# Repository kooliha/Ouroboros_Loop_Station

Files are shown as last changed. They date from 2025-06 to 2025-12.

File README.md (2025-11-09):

# ♾️ Ouroboros Loop Station
DIY 5-Track Audio Looper

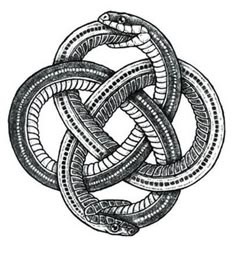
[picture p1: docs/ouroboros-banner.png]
Ouroboros Loop Station


Ouroboros is a DIY 5-track (Layers) stereo loop station designed for musicians, producers, and synth enthusiasts.
Built on the Electrosmith Daisy Seed platform, it offers real-time looping with zero menu diving — just buttons and knobs.

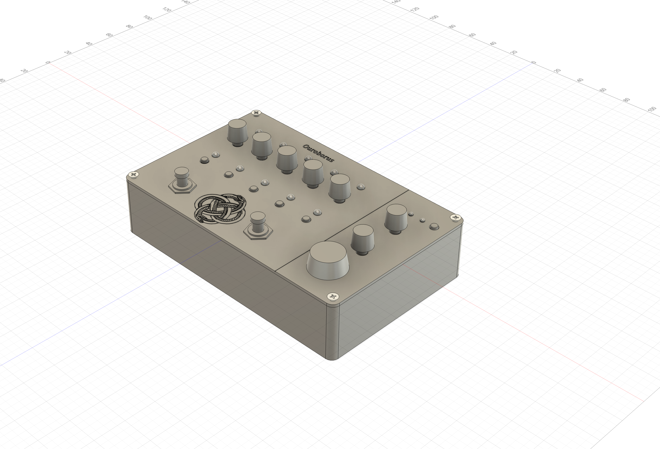
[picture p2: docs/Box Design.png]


## Key Features

- **5 independent stereo tracks** (33 seconds each at 48kHz)
- **Real-time per-track control**:
  - Speed: 0.3× to 2.0×
  - Pan: Left/Right positioning  
  - Volume: Individual + Master
- **Multi-input support**: Guitar, Mic, Line
- **Instant control** — no menus, just hold button + turn knob

## Audio I/O

- 🎸 **Guitar** (Hi-Z)
- 🎤 **Microphone** (with analog preamp)
- 🎧 **Stereo Line In**
- 🔊 **Stereo Output**

## Hardware

- **Daisy Seed** (STM32H750 microcontroller)
- **Through-hole components** only — easy to solder and mod
- **DIY-friendly design**

**Front Side:**
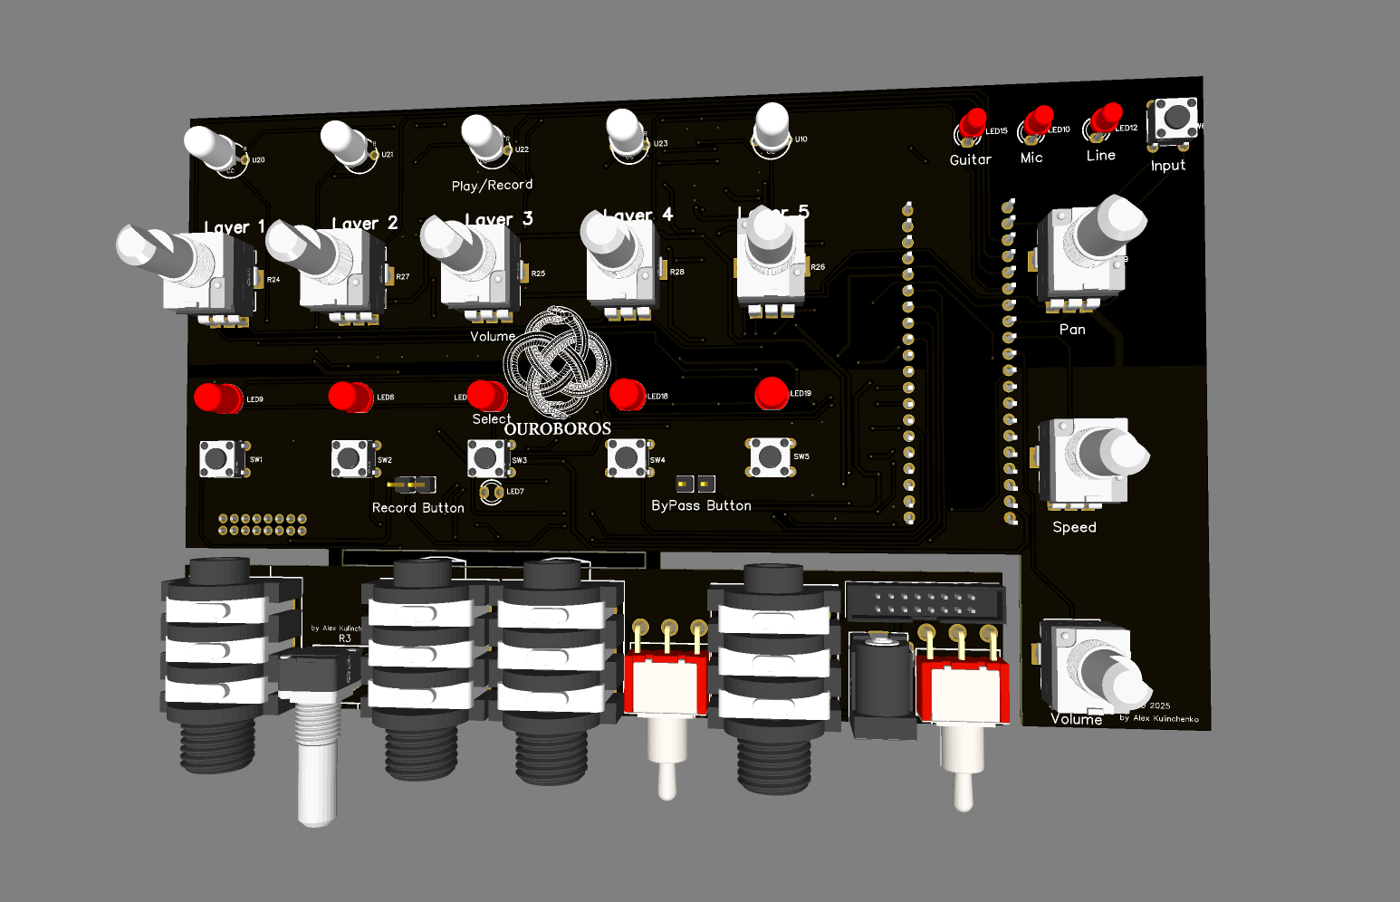
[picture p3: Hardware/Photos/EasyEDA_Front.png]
PCB Front


**Back Side:**
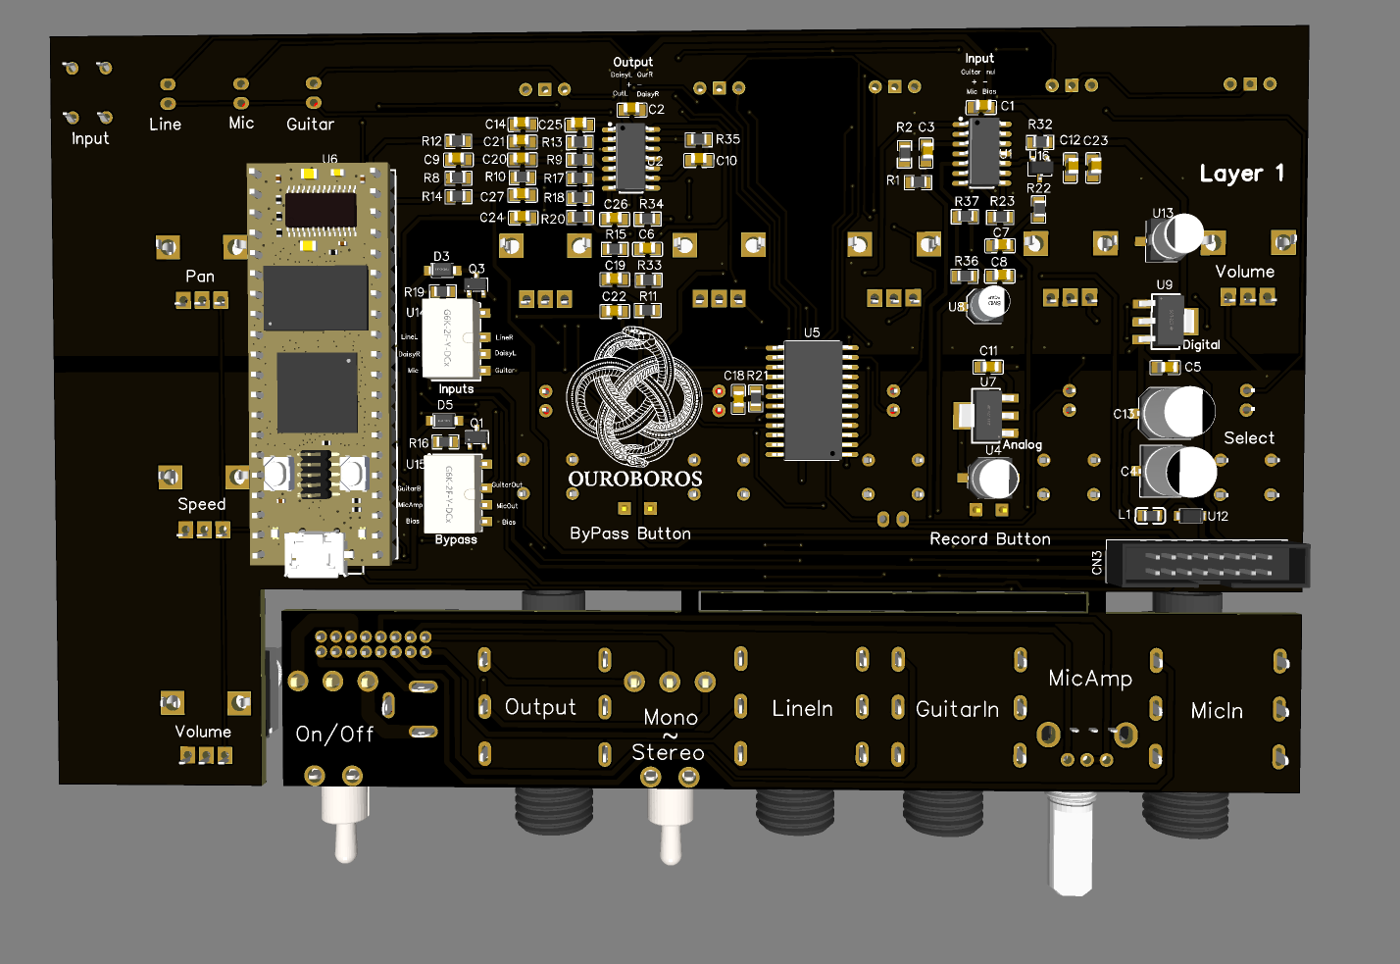
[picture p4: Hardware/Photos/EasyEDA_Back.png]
PCB Back


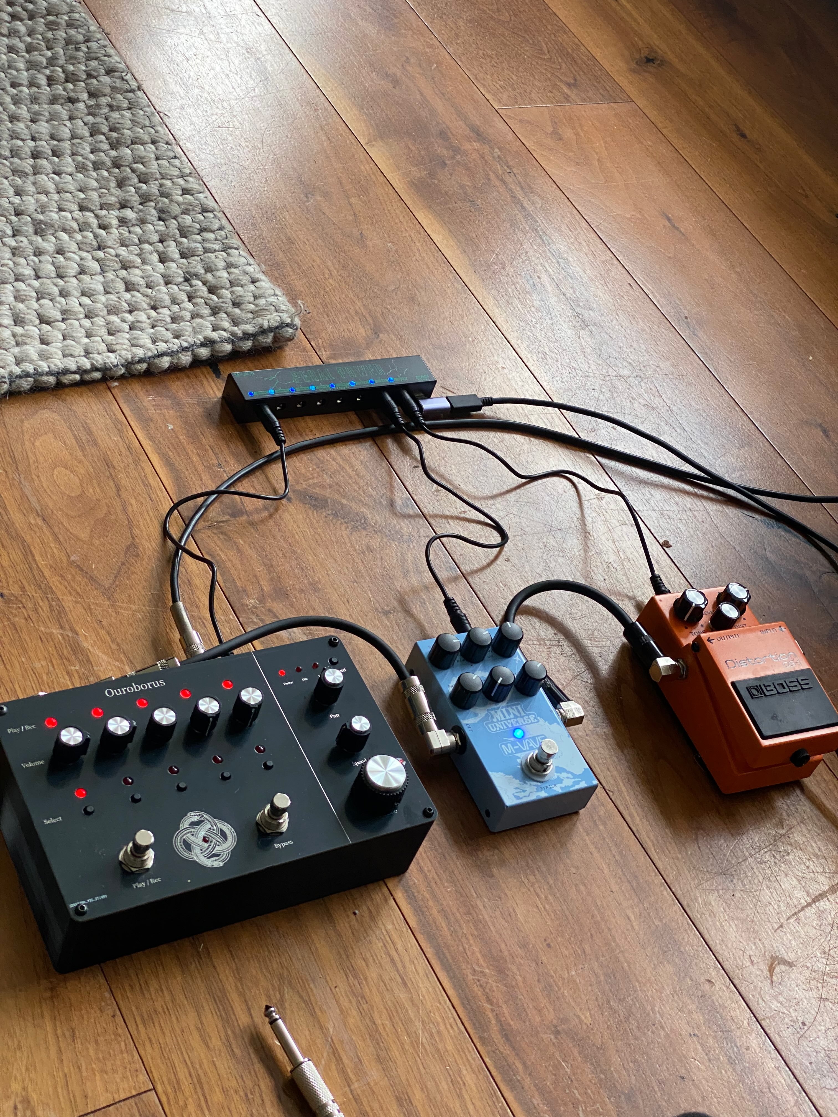
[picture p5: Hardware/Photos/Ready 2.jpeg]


## Hardware
It’s free to use. If you build one and fancy buying me a pint, you can do so here:

[Paypal](https://www.paypal.com/paypalme/AlexKulinchenko)

[Ko-fi.com](https://ko-fi.com/alex_kulinchenko)

Links

* **Schematic**: [PDF](Hardware/Ouroboros%20Schematic%20v1.1-1.2.pdf)
* **PCB v1.1 (Tested)**: [Gerber Files](Hardware/PCB%201.1/PCB_Gerber_1.1.zip)
* **PCB v1.2 (Beta)**: [Gerber Files](Hardware/PCB%201.2/PCB_Gerber_1.2.zip)
* **BOM**: [Excel File](Hardware/BOM_Ouroboros_rev.1.xlsx)
* **3D-printable enclosure**: [3D Files](Hardware/3d%20Printing%20Box%201.1/)
* **Front Panel**: [Design Files](Hardware/Front%20Panel%201.1-1.2/)

## Firmware

Ready-to-flash firmware is available in the `Firmware Master/` folder.

### Flashing Instructions

**Option 1: USB Mass Storage (Easiest)**
1. Download the `.bin` file from [Firmware Master](Firmware%20Master/)
2. Put Daisy Seed in USB Mass Storage mode:
   - Hold **BOOT** button
   - While holding BOOT, press and release **RESET** 
   - Release **BOOT** button
3. Daisy appears as USB drive on your computer
4. Drag and drop the `.bin` file to the USB drive
5. Firmware flashes automatically and Daisy restarts

**Option 2: DFU Flashing**
```bash
make program-dfu
```

**Building from Source**
```bash
make
# Creates main.bin in build/ folder
```

---

Release notes v1.1 (important)

* IDC 16-pin ribbon. I planned to use a standard IDC ribbon to simplify assembly, but I mistakenly used a 1.27 mm pitch instead of 2.54 mm. You’ll either need a matching cable or to hand-wire the connection.
* The output is stereo. Always use a stereo (TRS) jack — a mono plug will short one side of the op-amp. I’ve added protection, but it’s still best to use TRS.
* Analogue and digital grounds are separated and tied at a single point. You must bridge them under the Daisy Seed before power-up. I left this open for easier debugging.
* This PCB does not fit standard Hammond aluminium boxes as-is. Potentially, you can abandon PCB for a socket and fit it with just wires. A 3D-printable enclosure is included.

---

In progress — v1.2 (draft)

I’ve reworked the socket I/O board and corrected the IDC footprint. It should fit a larger Hammond enclosure. If anyone is willing to test the new PCB, you’re very welcome.

* **V1.2 files**: [PCB Gerber Files](Hardware/PCB%201.2/PCB_Gerber_1.2.zip)
* Notes:
  * Socket / I-O board fully redesigned (new layout, different switch/jack footprints).
  * IDC 16-pin footprint corrected; please confirm the pitch before fabrication.

When time allows (between work and family), I plan to design a single-board version combining the Daisy and I/O section, properly sized for a Hammond enclosure.

Feel free to ask questions – always happy to help.

## How to Use

### Recording a Track
1. **Select layer** - Press any layer button (1-5)
2. **Choose input** - Press channel button to cycle: Guitar → Mic → Line
3. **Record** - Hold record button to start recording
4. **Stop** - Release record button to stop and start playback

### Playback Control  
- **Play/Pause** - Single click record button
- **Clear track** - Double click record button
- **Volume** - Turn individual layer volume knob
- **Master volume** - Turn master volume knob

### Real-time Effects
- **Speed control** - Hold any layer button + turn speed knob
- **Pan control** - Hold any layer button + turn pan knob

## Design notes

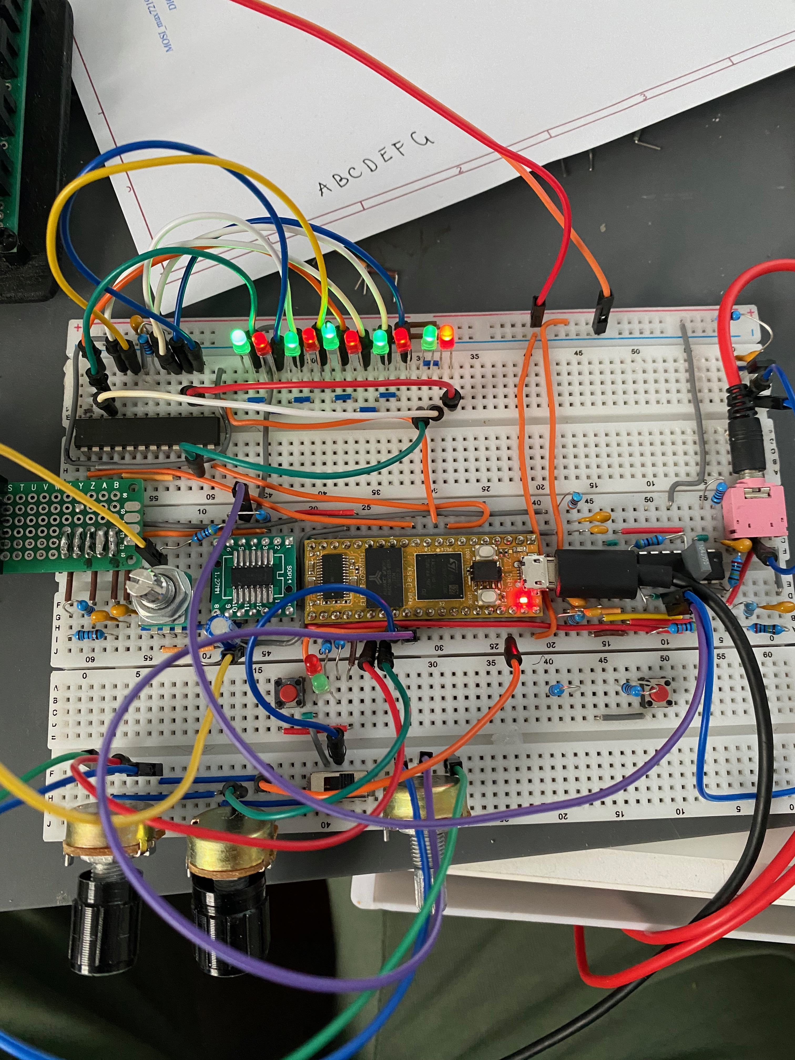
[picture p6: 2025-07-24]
Hardware/Photos/WIP.jpeg

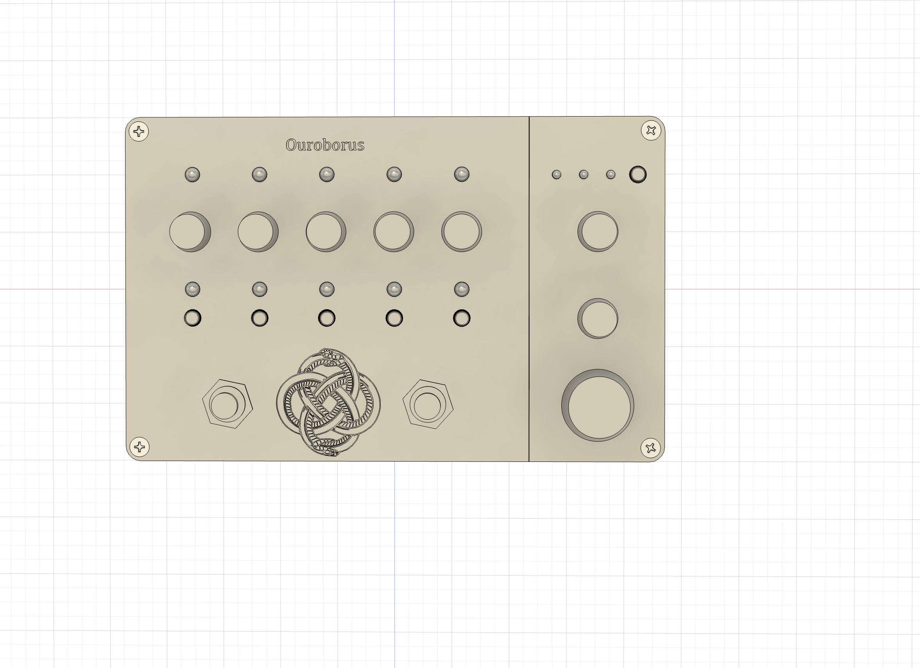
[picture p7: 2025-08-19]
docs/Box Design 2.png

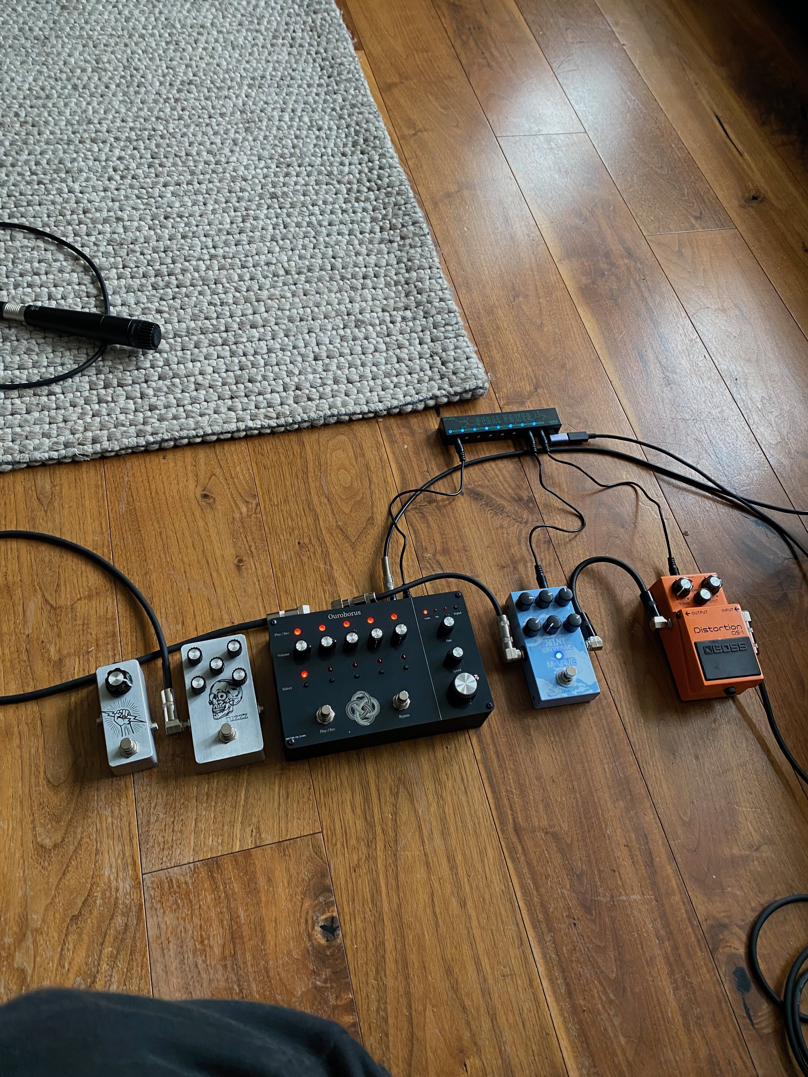
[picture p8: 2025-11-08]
Hardware/Photos/Ready.jpeg

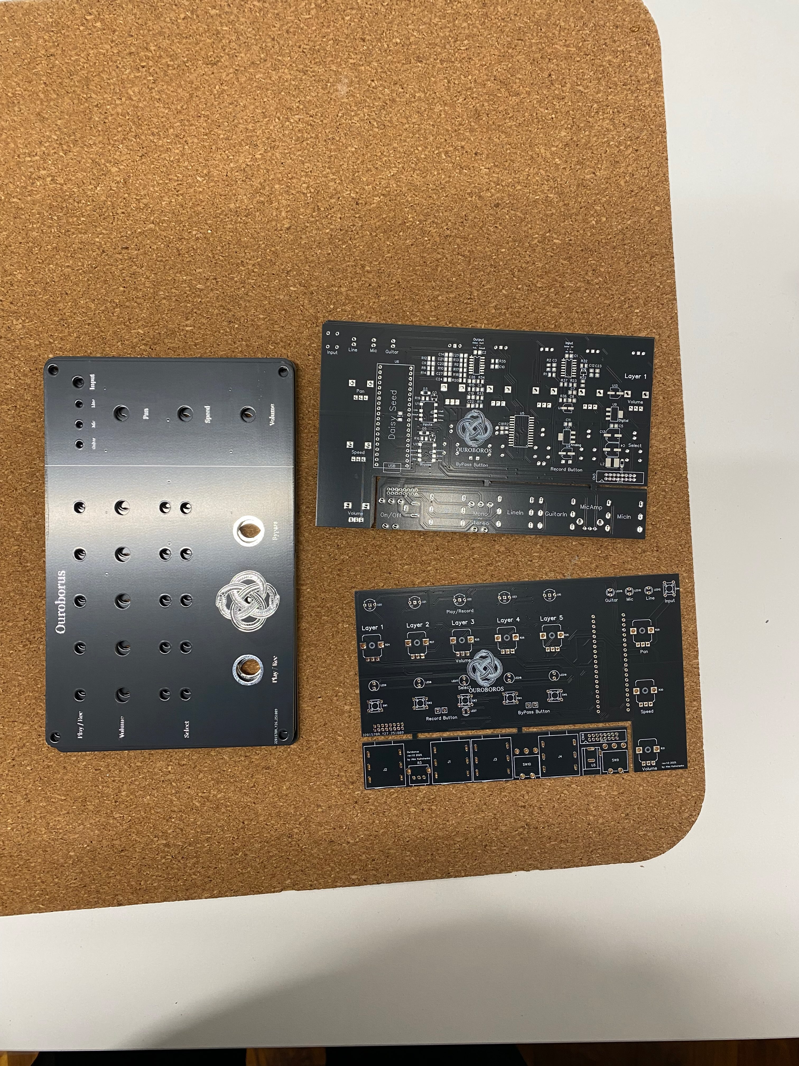
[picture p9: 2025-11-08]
Hardware/Photos/all PCB.jpeg

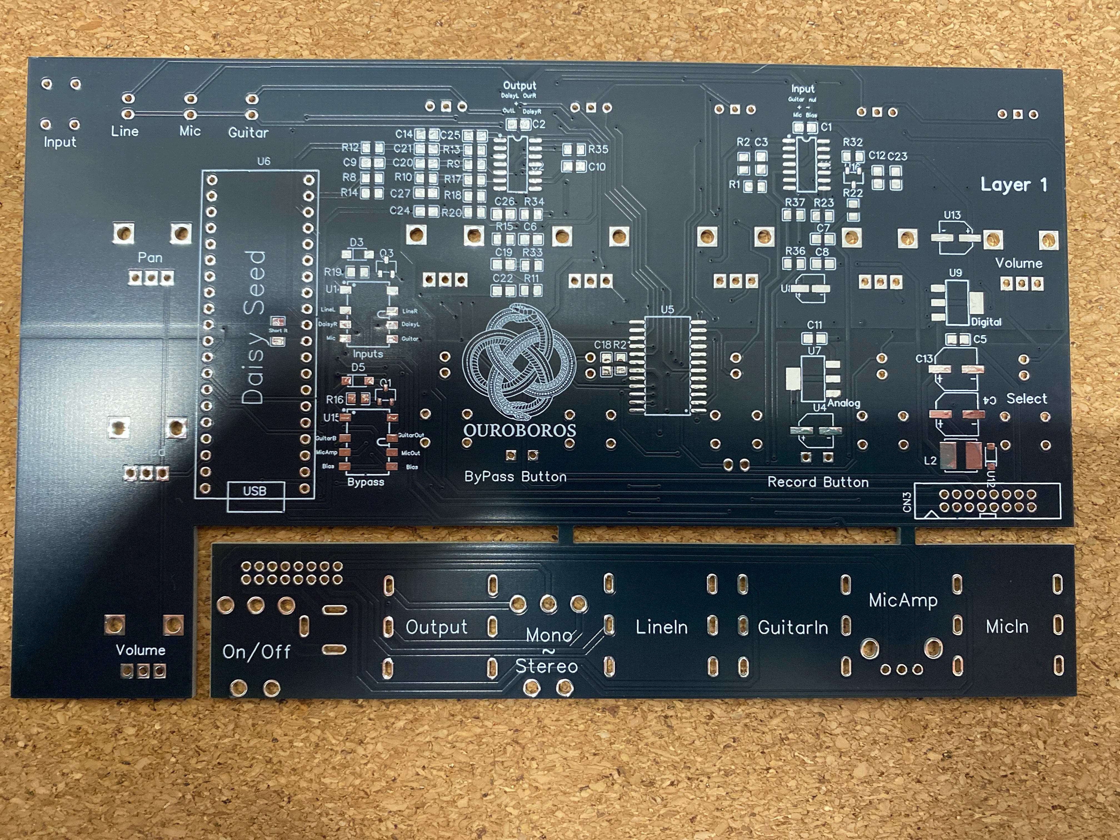
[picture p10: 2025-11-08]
Hardware/Photos/PCB Back.jpeg

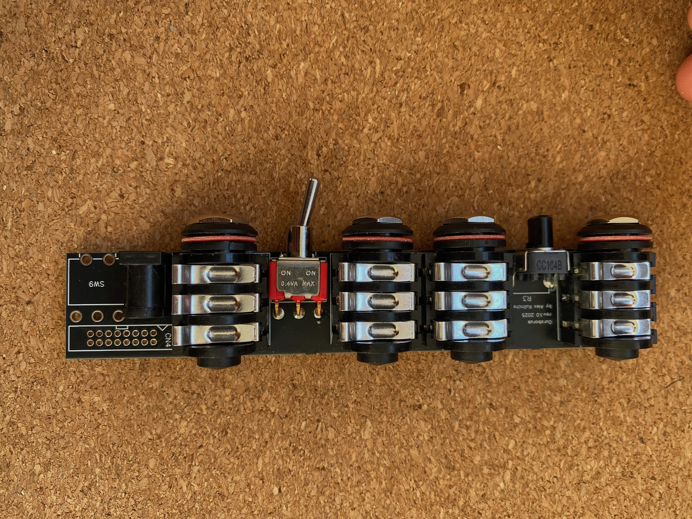
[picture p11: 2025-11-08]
Hardware/Photos/Sockets.jpeg

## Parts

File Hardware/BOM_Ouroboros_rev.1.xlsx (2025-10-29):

Name | Designator | Footprint | Quantity | LCSC- Manufacturer Part | LCSC - Manufacturer | LCSC- Supplier | LCSC - Supplier Part | Mouser_PN | Manufacturer | Supplier
100nF | C1,C2,C5,C11, C18 | C0805 | 5 | CT4-0805Y104M500 | ReliaPro | LCSC | C46756 | 80-C0805C104K5RACLR | ok | ok
10uf | C3,C7,C10,C20,C21,C22,C24,C25 | C0805 | 8 | CT4-0805Y104M500 | ReliaPro | LCSC | C46756 | 963-EMK212BB7106KG-T | ok | ok
47p | C6,C8,C26 | C0805 | 3 | CT4-0805Y104M500 | ReliaPro | LCSC | C46756 | 80-C0805C470K1HACTU | ok | ok
2.2nf | C9,C14 | C0805 | 2 | CT4-0805Y104M500 | ReliaPro | LCSC | C46756 | 80-C0805C222K5R | ok | ok
1uf | C12 | C0805 | 1 | CT4-0805Y104M500 | ReliaPro | LCSC | C46756 | 81-GRM40X105K16L | ok | ok
47uf | C19,C27 | C0805 | 2 | CT4-0805Y104M500 | ReliaPro | LCSC | C46756 | 603-CC805MKX5R5BB476 | ok | ok
0.01uf | C23 | C0805 | 1 | CT4-0805Y104M500 | ReliaPro | LCSC | C46756 | 80-C0805C103K5RAC | ok | ok
22uH | L1 | 5050 |  |  |  |  |  | 963-LCXHF5050WBT220M | ok | ok
2M | R1 | R0805 | 1 | RMC 0805 2M J N | Tyohm(幸亚电阻) | LCSC | C325853 | 603-RC0805FR-072ML | ok | ok
470k | R2,R9,R13,R23 | R0805 | 4 | RT0805BRD07470KL | YAGEO(国巨) | LCSC | C136922 | 603-RC0805FR-07470KL | ok | ok
Short it | R4 | Short it | 1
3.3k | R8,R12 | R0805 | 2 | RMC08053.3K1%N | Tyohm(幸亚电阻) | LCSC | C269541 | 603-RC0805FR-073K3L | ok | ok
100R | R10,R15,R32 | R0805 | 3 | CRCW0805100RJNEAC | VISHAY(威世) | LCSC | C3008930 | 603-RC0805FR-07100RL | ok | ok
100k | R11,R14,R17,R18,R20,R22,R33,R34,R35 | R0805 | 9 | AECR0805F100KK9 | RESI(开步睿思) | LCSC | C328379 | 71-RCA0805100KFKEA | ok | ok
1k | R16,R19,R36,R37 | R0805 | 4 | 0805W8F1001T5E | UNI-ROYAL(厚声) | LCSC | C17513 | 603-RC0805FR-071KL | ok | ok
10k | R21 | R0805 | 1 | SCR0805F10K | VO(翔胜) | LCSC | C3016734 | 603-RC0805FR-0710KL | ok | ok
2N3904 | Q1,Q3 | SOT-23-3_L3.0-W1.7-P0.95-LS2.9-BR | 2 | 2N3904S-HXY | HXY MOSFET(华轩阳电子) | LCSC | C46682376 | 863-MMBT3904LT1G | ok | ok
1N4007W | D3,D5, U12 | SOD-123FL_L2.7-W1.8-LS3.8-RD | 3 | 1N4007W | 晶导微电子 | LCSC | C108803 | 583-1N4007W-T | ok | ok
10uF | U8 | CAP-SMD_BD4.0-L4.3-W4.3-LS5.0-FD | 1 | 126RV0157 | KNSCHA(科尼盛) | LCSC | C7461288 | 710-865090340002 | ok | ok
100uF | C4,C13 | CAP-SMD_BD6.3-L6.6-W6.6-LS7.2-FD | 2 | RVT100UF16V67RV0016 | KNSCHA(科尼盛) | LCSC | C2887276 | 710-865080545012 | ok | ok
10uF | U4,U13 | CAP-SMD_BD5.0-L5.3-W5.3-LS5.5-FD | 2 | VZ1V100MC054000CE0 | HUAWEI(华威集团) | LCSC | C2912512 | 710-865230542002 | ok | ok
MAX7219M/TR | U5 | SOP-24_L15.4-W7.5-P1.27-LS10.4-BL | 1 | MAX7219M/TR | HGSEMI(华冠) | LCSC | C6705351 | https://www.aliexpress.com/item/1005008179077454.html?curPageLogUid=TpS2fnSt5gEw | LATER | Order
Daisy Seed | U6 | DAISY_SEED | 1
LD1117-5.0 | U7,U9 | SOT-223_L6.7-W3.5-P2.30-BR | 2 | LD1117-5.0 | UMW(友台半导体) | LCSC | C347230 | 511-LD1117S50C-TR | ok | ok
G6K-2F-Y-5V | U14,U15 | RELAY-SMD_G6K-2F-Y | 2 | G6K-2F-Y-5V | OMRON(欧姆龙) | LCSC | C2982926 | https://www.aliexpress.com/item/1005005223621224.html | ok
TL431 | U16 | SOT-23-3_L3.0-W1.6-P1.90-LS2.8-BR | 1 | TL431-SOT-23 | DDF(鼎德丰) | LCSC | C50229486 | 595-TL431BQDBZT | ok | ok
OPA1654 | U1,U2 | SOIC-14_L8.6-W3.9-P1.27-LS6.0-BL | 2 | OPA1654AID | TI(德州仪器) | LCSC | C2878588 | 595-OPA1654AID | ok | ok
TH Components
Guitar Input | J1 | AUDIO-TH_PJ-609AE | 1 | PJ-609AE环保 | HOOYA(皓宇电子) | LCSC | C309275
Mic Input | J2 | AUDIO-TH_PJ-609AE | 1 | PJ-609AE环保 | HOOYA(皓宇电子) | LCSC | C309275
LineInput | J3 | AUDIO-TH_PJ-609AE | 1 | PJ-609AE环保 | HOOYA(皓宇电子) | LCSC | C309275
Output | J4 | AUDIO-TH_PJ-609AE | 1 | PJ-609AE环保 | HOOYA(皓宇电子) | LCSC | C309275
Bypass | LED7 | LED_LED3MM | 1
L2_Selected | LED8 | LED-TH_BD5.0_RED | 1 | 333-2SURD/S530-A3 | EVERLIGHT(台湾亿光) | LCSC | C87271
L1_Selected | LED9 | LED-TH_BD5.0_RED | 1 | 333-2SURD/S530-A3 | EVERLIGHT(台湾亿光) | LCSC | C87271
Input: Mic | LED10 | LED_LED3MM | 1
Input: Line | LED12 | LED_LED3MM | 1
Input:Guitar | LED15 | LED_LED3MM | 1
L3_Selected | LED17 | LED-TH_BD5.0_RED | 1 | 333-2SURD/S530-A3 | EVERLIGHT(台湾亿光) | LCSC | C87271
L4_Selected | LED18 | LED-TH_BD5.0_RED | 1 | 333-2SURD/S530-A3 | EVERLIGHT(台湾亿光) | LCSC | C87271
L5_Selected | LED19 | LED-TH_BD5.0_RED | 1 | 333-2SURD/S530-A3 | EVERLIGHT(台湾亿光) | LCSC | C87271
100k | R3 | 9MM Horizontal Potentiometer RV09 | 1 | DIP-VR-3P-2.54MM-RV09 |  | LCSC | C9900014641
100k | R24,R25,R26,R27,R28,R29,R30,R31 | 9MM Vertical Potentiometer | 8 | SCR0805J10K | VO(翔胜) | LCSC | C5140188
push-button | SW1, SW2, SW3, SW4, SW5, SW6 | SW-TH_SH-6X6X4.3H-CJ | 1 | SH-6X6X4.3H-CJ | SHOU HAN(首韩) | LCSC | C42416242
Toggle Switch SPDT | SW9, SW10 | SW-TH_1MS1T2B4M6QES | 1 | 1MS1T2B4M6QES | Dailywell(德利威) | LCSC | C545199
Power Socket | U3 | DC-IN-TH_DC-005-A200 | 1 | DC-005-A20 | Yuandi(元迪) | LCSC | C19077752
L5_Play_Rec_Led | U10 | DUAL LED COMMON CATHODE R/B | 1
L1_Play_Rec_Led | U20 | DUAL LED COMMON CATHODE R/B | 1
L2_Play_Rec_Led | U21 | DUAL LED COMMON CATHODE R/B | 1
L3_Play_Rec_Led | U22 | DUAL LED COMMON CATHODE R/B | 1
L4_Play_Rec_Led | U23 | DUAL LED COMMON CATHODE R/B | 1
LED Spacer 7.62mm for 3mm LEDs | SPACER-3MM | LED-SPACER-3MM | 3 |  |  |  |  | 749-ERM1-300
LED Spacer 8mm for 5mm LEDs | SPACER-5MM | LED-SPACER-5MM | 4 |  |  |  |  | 749-ERM1-8MM
LED Spacer 8mm for 5mm 3-lead LEDs | SPACER-5MM-3L | LED-SPACER-5MM-3LEAD | 5 |  |  |  |  | 749-ERM1-8MM
Tactile Switch Cap 5mm for 6x6mm | SWCAP-BK | SWITCH-CAP_6x6_BK | 6 |  |  |  |  | 612-1R-BK
16 Pin socket |  |  | 2

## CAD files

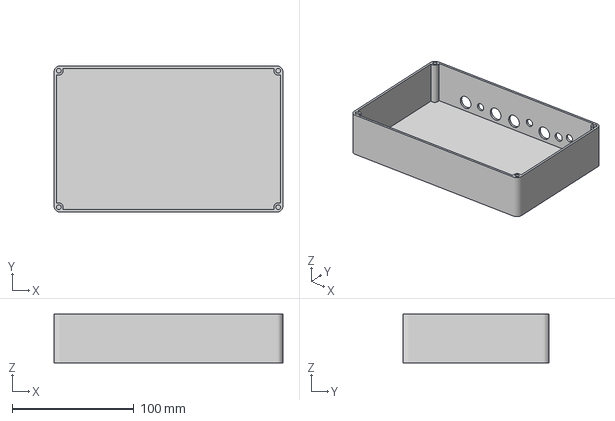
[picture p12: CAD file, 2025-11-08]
Hardware/3d Printing Box 1.1/Ouroboros 3d Box.3mf
188.0 x 120.0 x 40.0 mm

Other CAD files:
Hardware/3d Printing Box 1.1/Ouroboros 3dBox_Cura.3mf
Hardware/3d Printing Box 1.1/Ouroboros 3d Box.obj

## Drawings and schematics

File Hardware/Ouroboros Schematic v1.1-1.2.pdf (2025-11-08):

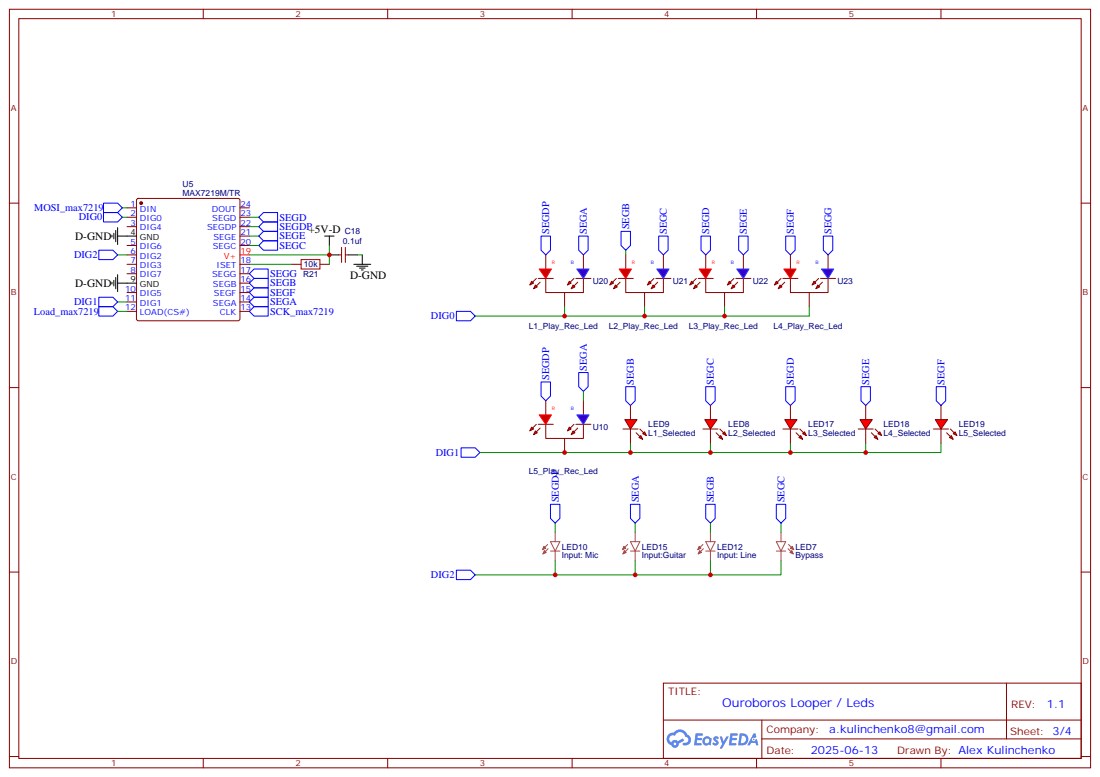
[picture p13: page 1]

Drawn By: Alex Kulinchenko

## U1.1¹¹

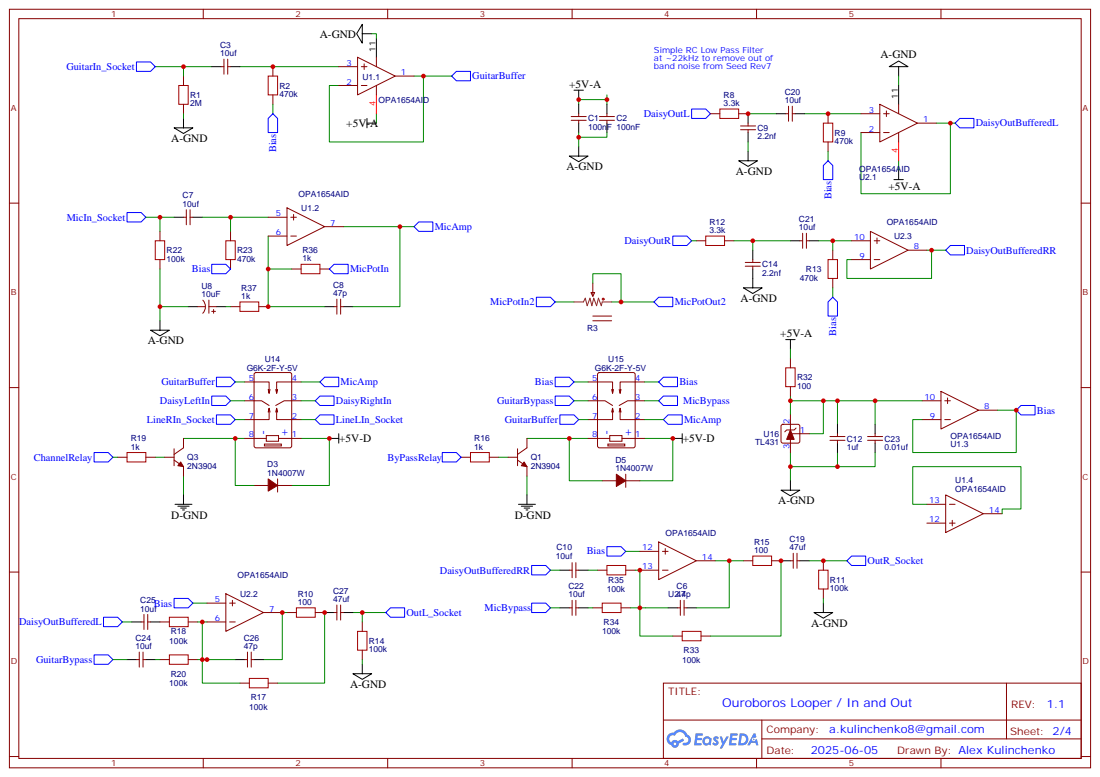
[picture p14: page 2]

Simple RC Low Pass Filter
at ~22kHz to remove out of
band noise from Seed Rev7

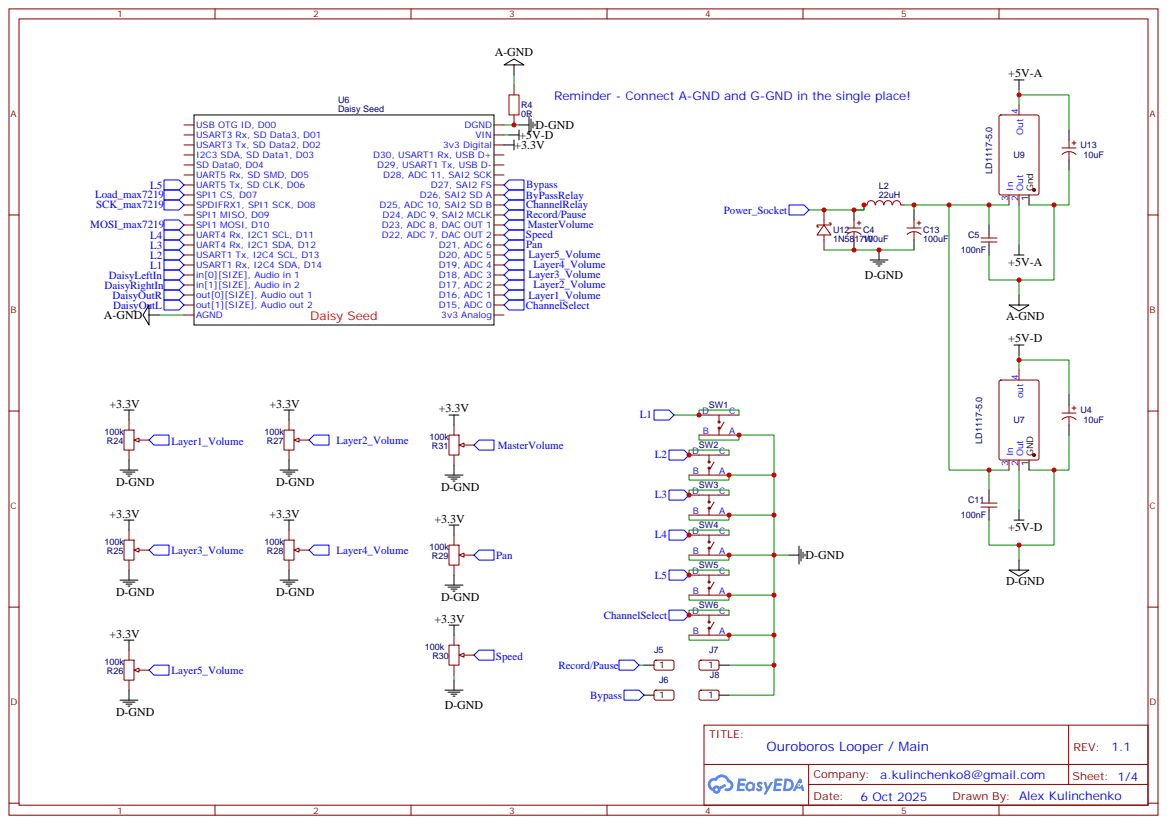
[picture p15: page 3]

USB OTG ID, D00
USART3 Rx, SD Data3, D01
USART3 Tx, SD Data2, D02
I2C3 SDA, SD Data1, D03
SD Data0, D04
UART5 Rx, SD SMD, D05
UART5 Tx, SD CLK, D06
SPI1 CS, D07
SPDIFRX1, SPI1 SCK, D08
SPI1 MISO, D09
SPI1 MOSI, D10
UART4 Rx, I2C1 SCL, D11
UART4 Rx, I2C1 SDA, D12
USART1 Tx, I2C4 SCL, D13
USART1 Rx, I2C4 SDA, D14
in[0][SIZE], Audio in 1
in[1][SIZE], Audio in 2
out[0][SIZE], Audio out 1
out[1][SIZE], Audio out 2

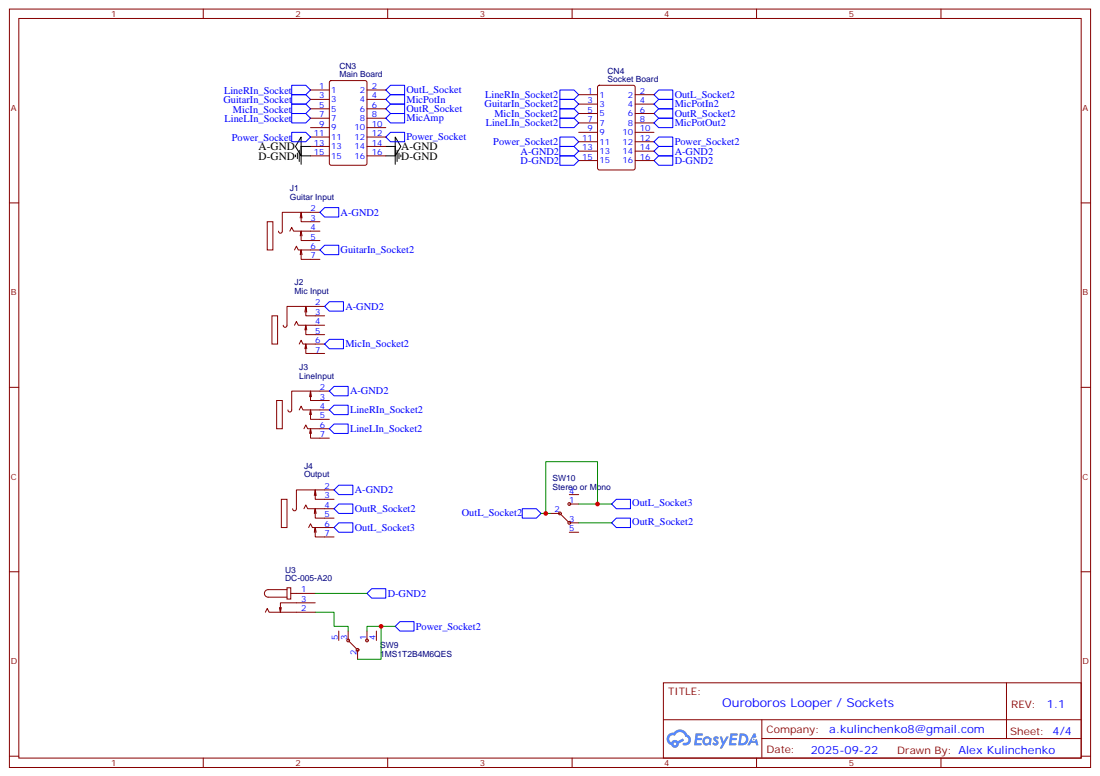
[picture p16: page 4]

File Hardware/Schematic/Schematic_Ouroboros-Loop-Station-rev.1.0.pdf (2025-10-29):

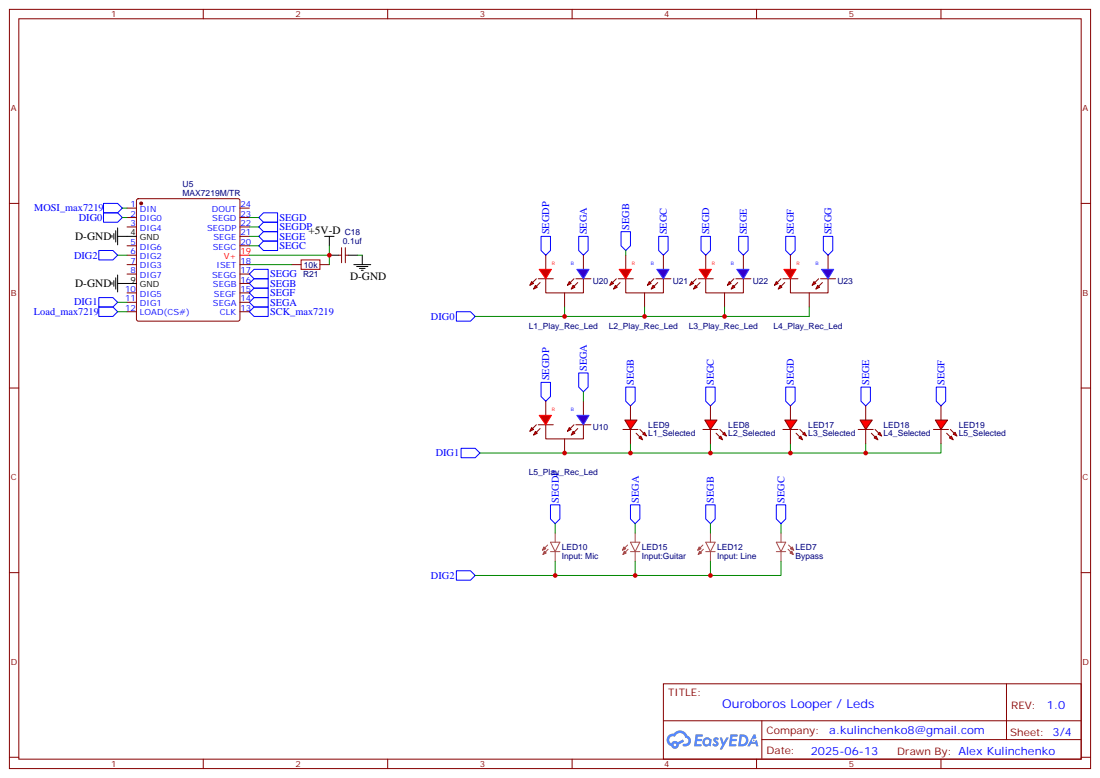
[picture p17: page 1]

Drawn By: Alex Kulinchenko

# U1.1¹¹

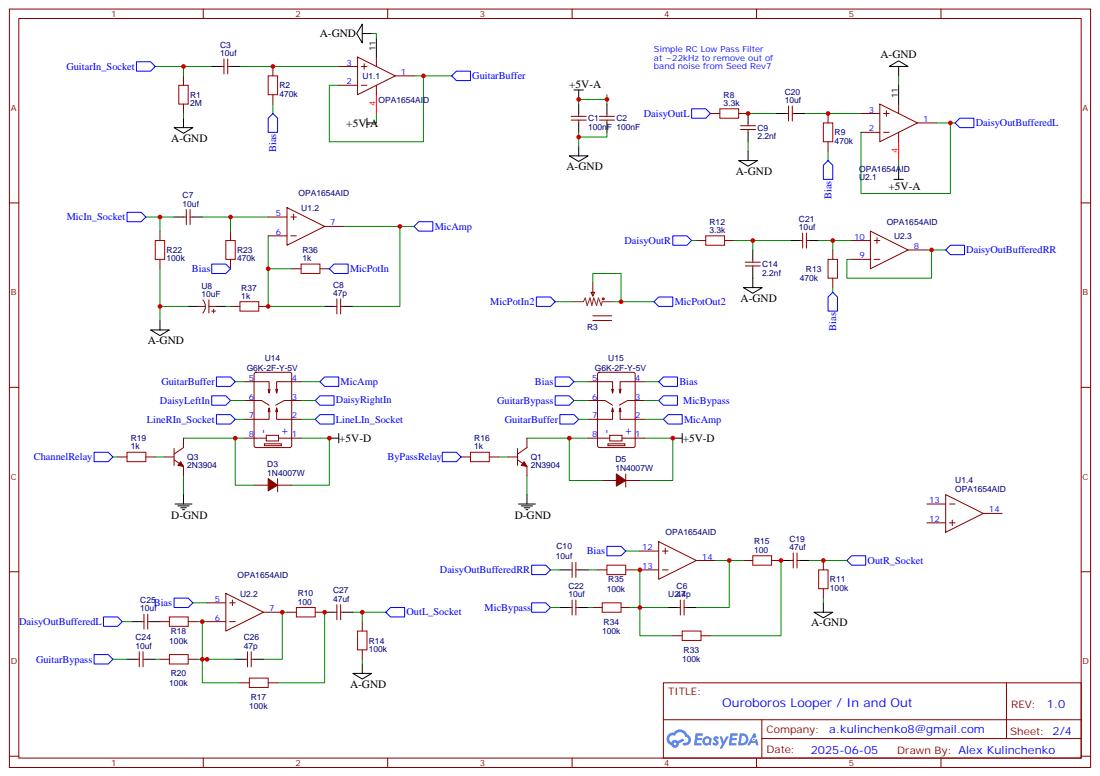
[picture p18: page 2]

Simple RC Low Pass Filter
at ~22kHz to remove out of
band noise from Seed Rev7

## Reminder - Connect A-GND and G-GND in the single place!

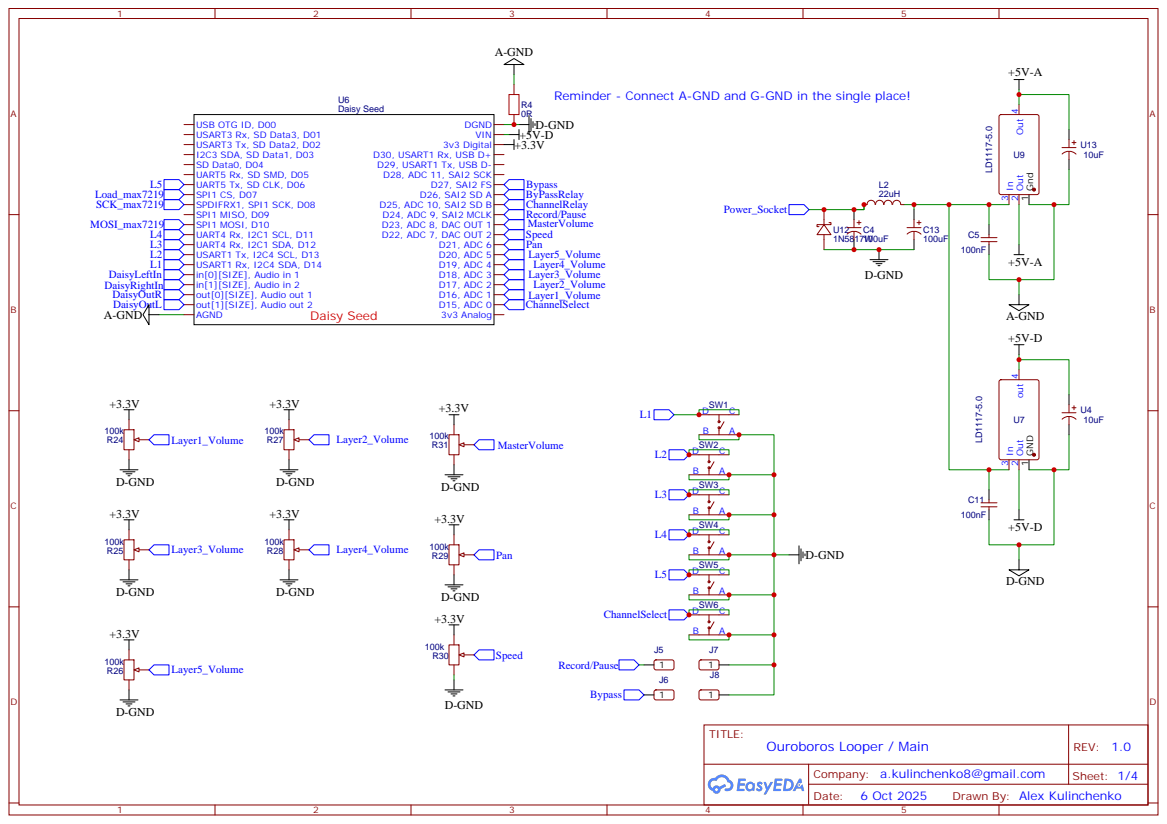
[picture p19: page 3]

USB OTG ID, D00
USART3 Rx, SD Data3, D01
USART3 Tx, SD Data2, D02
I2C3 SDA, SD Data1, D03
SD Data0, D04
UART5 Rx, SD SMD, D05
UART5 Tx, SD CLK, D06
SPI1 CS, D07
SPDIFRX1, SPI1 SCK, D08
SPI1 MISO, D09
SPI1 MOSI, D10
UART4 Rx, I2C1 SCL, D11
UART4 Rx, I2C1 SDA, D12
USART1 Tx, I2C4 SCL, D13
USART1 Rx, I2C4 SDA, D14
in[0][SIZE], Audio in 1
in[1][SIZE], Audio in 2
out[0][SIZE], Audio out 1
out[1][SIZE], Audio out 2

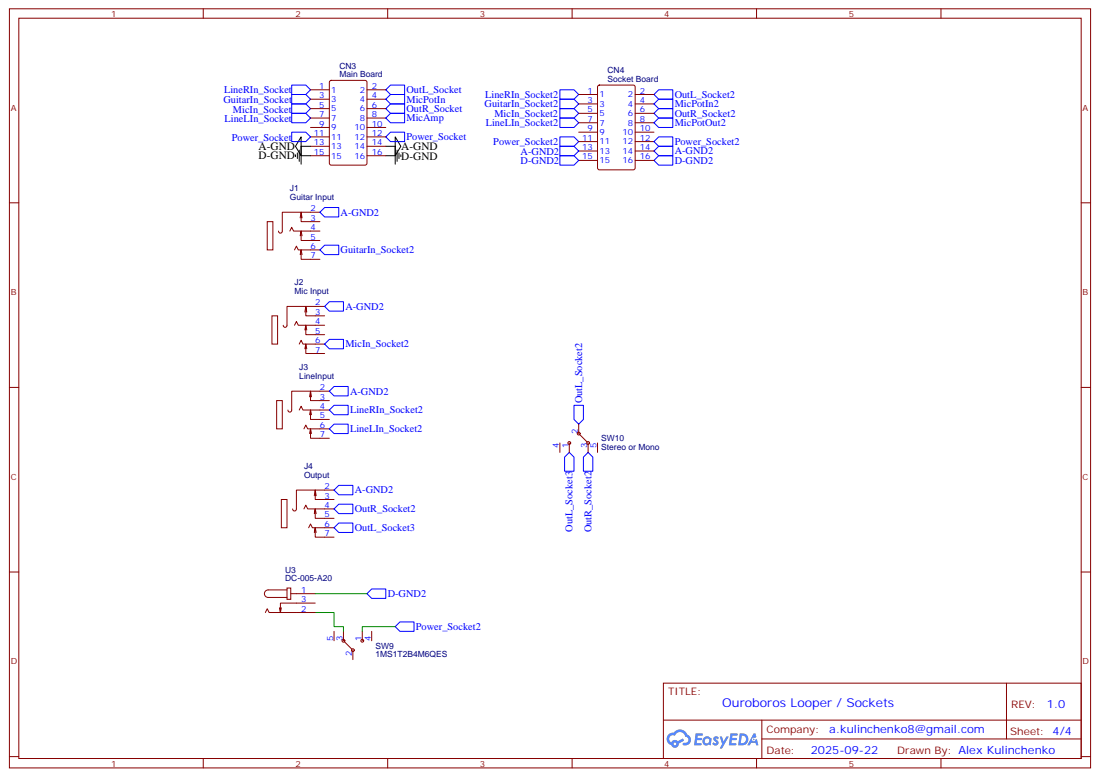
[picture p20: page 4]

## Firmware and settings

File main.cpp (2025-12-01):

#include "daisy_seed.h"
#include "daisysp.h"
#include "max7219.h"
#include "looper_layer.h"
#include <cmath>

using namespace daisy;
using namespace daisy::seed;
using namespace daisysp;

#ifndef M_PI
#define M_PI 3.14159265358979323846
#endif

#define kBuffSize 1600000 // ~33 seconds at 48kHz per each layer (5 in total)
#define kNumLayers 5

// ===== PIN DEFINITIONS =====
// SPI pins for MAX7219 LED driver
constexpr Pin SPI_SCLK = D8;
constexpr Pin SPI_MISO = D9;
constexpr Pin SPI_MOSI = D10;
constexpr Pin SPI_CS   = D7;

// Control buttons
constexpr Pin RECORD_PLAY_BTN = D24;
constexpr Pin CHANNEL_BTN     = D15;

// Layer select buttons
constexpr Pin LAYER1_BTN = D14;
constexpr Pin LAYER2_BTN = D13;
constexpr Pin LAYER3_BTN = D12;
constexpr Pin LAYER4_BTN = D11;
constexpr Pin LAYER5_BTN = D6;

// Channel switch relay pin
constexpr Pin CHANNEL_SWITCH_RELAY = D25;

// Bypass relay and button pins
constexpr Pin BYPASS_RELAY = D26; // Analog bypass relay (OFF = only loop, ON = loop + wet signal)
constexpr Pin BYPASS_BTN   = D27; // Push button to toggle bypass

// ADC pins for knobs
constexpr Pin SPEED_POT  = D22;  // Common speed control
constexpr Pin PAN_POT    = D21;  // Common pan control (updated for PCB)
constexpr Pin MASTER_VOL = D23;  // Master volume for all layers (updated for PCB)

// Individual volume pots per layer
constexpr Pin VOLUME1_POT = D16; // Layer 1 volume
constexpr Pin VOLUME2_POT = D17; // Layer 2 volume  
constexpr Pin VOLUME3_POT = D18; // Layer 3 volume
constexpr Pin VOLUME4_POT = D19; // Layer 4 volume
constexpr Pin VOLUME5_POT = D20; // Layer 5 volume

DaisySeed hw;
Max7219 LedDriver;

float DSY_SDRAM_BSS buffer_l[kNumLayers][kBuffSize];
float DSY_SDRAM_BSS buffer_r[kNumLayers][kBuffSize];

LooperLayer layers[kNumLayers];

Switch record_play_button;
Switch layer1_select_button;
Switch layer2_select_button;
Switch layer3_select_button;
Switch layer4_select_button;
Switch layer5_select_button;

Switch channel_button;

// Bypass control
Switch bypass_button;

// Channel switch relay
GPIO channel_switch_relay; // D25 - ON = Mic/Guitar, OFF = Line input

// Bypass relay
GPIO bypass_relay; // D26 - Write(false) = bypass active, Write(true) = bypass off

// Layer selection
int selected_layer = 0; // 0 = Layer 1, 1 = Layer 2, ..., 4 = Layer 5

// Input selection
int selected_channel = 0; // Default: 1 = Guitar, then 0 = Mic, 2 = Line
bool channel_override_active = false; // True when user has manually changed channel

// Bypass state
bool bypass_active = true; // True = loop + wet signal, False = only loop

// Metronome state
bool metronome_active = false;  // Metronome on/off
float metronome_bpm = 120.0f;   // Current BPM (40-250 range)
uint32_t metronome_sample_counter = 0;  // Sample counter for metronome timing
uint32_t samples_per_beat = 0;  // Calculated from BPM
int metronome_beat = 0;  // Current beat in 4/4 time (0=beat 1, 1=beat 2, etc.)
const int CLICK_DURATION_MS = 5;  // Click duration in milliseconds
uint32_t click_samples_remaining = 0;  // Countdown for click duration
bool is_downbeat = false;  // True for beat 1 (accent)

void SetupHardware()
{
    hw.Configure();
    hw.Init();

    // SPI configuration for Daisy Seed rev 7
    SpiHandle::Config spi_cfg;
    spi_cfg.periph = SpiHandle::Config::Peripheral::SPI_1;
    spi_cfg.mode   = SpiHandle::Config::Mode::MASTER;
    spi_cfg.direction = SpiHandle::Config::Direction::TWO_LINES_TX_ONLY;
    spi_cfg.datasize  = 8;
    spi_cfg.clock_polarity  = SpiHandle::Config::ClockPolarity::LOW;
    spi_cfg.clock_phase     = SpiHandle::Config::ClockPhase::ONE_EDGE;
    spi_cfg.nss             = SpiHandle::Config::NSS::SOFT;
    spi_cfg.baud_prescaler  = SpiHandle::Config::BaudPrescaler::PS_64;
    spi_cfg.pin_config.sclk = SPI_SCLK;
    spi_cfg.pin_config.miso = SPI_MISO;
    spi_cfg.pin_config.mosi = SPI_MOSI;

    static SpiHandle spi;
    spi.Init(spi_cfg);

    LedDriver.Init(&spi, SPI_CS);

    // Main controls (shared)
    record_play_button.Init(RECORD_PLAY_BTN, 300);        // Record/Play button

    // Layer select buttons
    layer1_select_button.Init(LAYER1_BTN, 300); // Layer 1 select button
    layer2_select_button.Init(LAYER2_BTN, 300); // Layer 2 select button
    layer3_select_button.Init(LAYER3_BTN, 300); // Layer 3 select button
    layer4_select_button.Init(LAYER4_BTN, 300); // Layer 4 select button
    layer5_select_button.Init(LAYER5_BTN, 300); // Layer 5 select button

    channel_button.Init(CHANNEL_BTN, 300); // Channel select button, fast debounce
    bypass_button.Init(BYPASS_BTN, 300);   // Bypass toggle button

    // Initialize channel switch relay
    channel_switch_relay.Init(CHANNEL_SWITCH_RELAY, GPIO::Mode::OUTPUT);
    
    // Start with relay ON (this gives Guitar/Mic input)
    channel_switch_relay.Write(true);

    // Initialize bypass relay
    bypass_relay.Init(BYPASS_RELAY, GPIO::Mode::OUTPUT);
    
    // Start with bypass ON
    bypass_relay.Write(false);

    // ADC pins: 3 common controls + 5 individual volume controls = 8 total
    daisy::Pin adc_pins[8] = {SPEED_POT, PAN_POT, MASTER_VOL, VOLUME1_POT, VOLUME2_POT, VOLUME3_POT, VOLUME4_POT, VOLUME5_POT};
    AdcChannelConfig adc_cfgs[8];
    for(int i = 0; i < 8; i++)
        adc_cfgs[i].InitSingle(adc_pins[i]);
    hw.adc.Init(adc_cfgs, 8);
    hw.adc.Start();

    // Layer buffers
    for(int i = 0; i < kNumLayers; i++)
    {
        layers[i].buffer_l = buffer_l[i];
        layers[i].buffer_r = buffer_r[i];
        layers[i].buffer_size = kBuffSize;
        layers[i].paused = false;
    }
}

void UpdateChannelLEDs()
{
    int channel_to_show;
    
    // If user has manually changed channel, show the selected_channel
    // Otherwise, show the recorded channel for recorded layers
    if(channel_override_active || !layers[selected_layer].recorded)
        channel_to_show = selected_channel;
    else
        channel_to_show = layers[selected_layer].recorded_channel;

    uint8_t segs = 0x00;
    if(channel_to_show == 0) segs = LED_CHANNEL_MIC.segment;    // Channel 0 = Mic
    else if(channel_to_show == 1) segs = LED_CHANNEL_GUITAR.segment; // Channel 1 = Guitar
    else if(channel_to_show == 2) segs = LED_CHANNEL_LINE.segment;   // Channel 2 = Line

    // Add bypass LED if bypass is active
    if(bypass_active) segs |= LED_BYPASS.segment; // SegC Dig2
    
    // Blink bypass LED when metronome is active (override solid bypass LED)
    if(metronome_active)
    {
        // Blink at metronome tempo (on during beat, off between beats)
        uint32_t blink_threshold = samples_per_beat / 4;  // LED on for 1/4 of beat duration
        if(metronome_sample_counter < blink_threshold)
        {
            segs |= LED_BYPASS.segment;  // Force LED on during beat
        }
        else
        {
            segs &= ~LED_BYPASS.segment;  // Force LED off between beats
        }
    }

    LedDriver.Send(LED_CHANNEL_GUITAR.digit, segs); // All are on Dig2
}

void UpdateRelays()
{
    // Control channel switch relay based on selected channel
    // Channel 0/1 = Mic/Guitar (relay ON), Channel 2 = Line (relay OFF)
    
    if(selected_channel == 2) // Line input
    {
        channel_switch_relay.Write(false);  // Deactivate relay for line input
    }
    else // Mic or Guitar input
    {
        channel_switch_relay.Write(true);   // Activate relay for mic/guitar input
    }
}

void UpdateLEDs()
{
    uint8_t segs_dig0 = 0x00;
    uint8_t segs_dig1 = 0x00;

    // Dig0: Recording/playing status for layers 1-4
    if(layers[0].recording) segs_dig0 |= LED_LAYER1_REC.segment;
    if(layers[0].recorded && !layers[0].recording && !layers[0].paused) segs_dig0 |= LED_LAYER1_PLAY.segment;
    if(layers[1].recording) segs_dig0 |= LED_LAYER2_REC.segment;
    if(layers[1].recorded && !layers[1].recording && !layers[1].paused) segs_dig0 |= LED_LAYER2_PLAY.segment;
    if(layers[2].recording) segs_dig0 |= LED_LAYER3_REC.segment;
    if(layers[2].recorded && !layers[2].recording && !layers[2].paused) segs_dig0 |= LED_LAYER3_PLAY.segment;
    if(layers[3].recording) segs_dig0 |= LED_LAYER4_REC.segment;
    if(layers[3].recorded && !layers[3].recording && !layers[3].paused) segs_dig0 |= LED_LAYER4_PLAY.segment;

    // Dig1: Layer 5 play/rec
    if(layers[4].recording) segs_dig1 |= LED_LAYER5_REC.segment;
    if(layers[4].recorded && !layers[4].recording && !layers[4].paused) segs_dig1 |= LED_LAYER5_PLAY.segment;

    // Dig1: Selected layer indicator for all layers
    if(selected_layer == 0) segs_dig1 |= LED_LAYER1_Selected.segment;
    if(selected_layer == 1) segs_dig1 |= LED_LAYER2_Selected.segment;
    if(selected_layer == 2) segs_dig1 |= LED_LAYER3_Selected.segment;
    if(selected_layer == 3) segs_dig1 |= LED_LAYER4_Selected.segment;
    if(selected_layer == 4) segs_dig1 |= LED_LAYER5_Selected.segment;

    LedDriver.Send(LED_LAYER1_PLAY.digit, segs_dig0); // Dig0
    LedDriver.Send(LED_LAYER1_Selected.digit, segs_dig1); // Dig1
}

void AudioCallback(AudioHandle::InputBuffer in,
                   AudioHandle::OutputBuffer out,
                   size_t size)
{
    for(size_t i = 0; i < size; i++)
    {
        out[0][i] = 0.0f;
        out[1][i] = 0.0f;
    }

    // === METRONOME PROCESSING ===
    if(metronome_active)
    {
        // Read speed knob only if no layer button is held (layer speed control has priority)
        bool any_layer_button_held = false;
        Switch* buttons[5] = {&layer1_select_button, &layer2_select_button, &layer3_select_button, &layer4_select_button, &layer5_select_button};
        for(int i = 0; i < kNumLayers; i++)
        {
            if(buttons[i]->Pressed() && buttons[i]->TimeHeldMs() > 200)
            {
                any_layer_button_held = true;
                break;
            }
        }
        
        if(!any_layer_button_held)
        {
            // Speed knob controls metronome BPM: 40-250 BPM range
            float speed_pot = 1.0f - hw.adc.GetFloat(0);  // Inverted (pots wired backwards)
            metronome_bpm = 40.0f + (speed_pot * 210.0f);  // 40 + (0-1 * 210) = 40-250
        }
        
        // Calculate samples per beat based on BPM
        float sample_rate = hw.AudioSampleRate();
        samples_per_beat = (uint32_t)((60.0f / metronome_bpm) * sample_rate);
        
        // Read master volume for metronome output level
        float master_vol = 1.0f - hw.adc.GetFloat(2);  // Inverted
        float master_volume = powf(master_vol, 2.5f) * 1.43f;
        
        // Process each sample
        for(size_t i = 0; i < size; i++)
        {
            // Check if we need to trigger a new beat
            if(metronome_sample_counter >= samples_per_beat)
            {
                metronome_sample_counter = 0;
                metronome_beat = (metronome_beat + 1) % 4;  // 4/4 time
                is_downbeat = (metronome_beat == 0);
                
                // Start click
                click_samples_remaining = (uint32_t)((CLICK_DURATION_MS / 1000.0f) * sample_rate);
            }
            
            // Generate click sound if active
            if(click_samples_remaining > 0)
            {
                // Simple click: short sine burst at 1000 Hz
                float click_freq = 1000.0f;
                float phase = (float)(click_samples_remaining) / sample_rate * click_freq * 2.0f * M_PI;
                
                // Amplitude: downbeat louder (0.3) than other beats (0.15)
                float amplitude = is_downbeat ? 0.3f : 0.15f;
                
                // Envelope: quick decay
                float envelope = (float)click_samples_remaining / (click_samples_remaining + 1);
                
                float click_sample = sinf(phase) * amplitude * envelope * master_volume;
                
                // Add to output (not recorded, just monitoring)
                out[0][i] += click_sample;
                out[1][i] += click_sample;
                
                click_samples_remaining--;
            }
            
            metronome_sample_counter++;
        }
    }

    // Layer select buttons debounce and switching
    layer1_select_button.Debounce();
    layer2_select_button.Debounce();
    layer3_select_button.Debounce();
    layer4_select_button.Debounce();
    layer5_select_button.Debounce();

    static bool last_layer_btn[5] = {false, false, false, false, false};
    bool layer_btn_pressed[5] = {
        layer1_select_button.Pressed(),
        layer2_select_button.Pressed(),
        layer3_select_button.Pressed(),
        layer4_select_button.Pressed(),
        layer5_select_button.Pressed()
    };

    // Check for layer button hold + speed/pan knob interaction
    int speed_controlled_layer = -1; // Which layer is having its speed controlled
    int pan_controlled_layer = -1;   // Which layer is having its pan controlled
    for(int i = 0; i < kNumLayers; i++)
    {
        // If button is held for more than 200ms, allow speed/pan control for this layer
        Switch* buttons[5] = {&layer1_select_button, &layer2_select_button, &layer3_select_button, &layer4_select_button, &layer5_select_button};
        if(buttons[i]->Pressed() && buttons[i]->TimeHeldMs() > 200)
        {
            speed_controlled_layer = i;
            pan_controlled_layer = i;
            break; // Only one layer can be speed/pan-controlled at a time
        }
    }

    // Handle layer selection (only on button press, not during speed control)
    for(int i = 0; i < kNumLayers; i++)
    {
        // Only switch layers on button press (not hold for speed/pan control)
        if(!last_layer_btn[i] && layer_btn_pressed[i] && speed_controlled_layer == -1 && pan_controlled_layer == -1)
        {
            selected_layer = i;
            channel_override_active = false; // Reset override when switching layers
            // Set selected_channel to match the recorded channel (if any)
            if(layers[selected_layer].recorded)
                selected_channel = layers[selected_layer].recorded_channel;
            UpdateRelays(); // Update relay state when switching layers
        }
        last_layer_btn[i] = layer_btn_pressed[i];
    }

    // Process main controls for selected layer
    layers[selected_layer].Process(
        selected_layer, // ADC offset: layer 0 uses volume at index 2, layer 1 at index 3, etc.
        in, out, size,
        &record_play_button,
        &hw,
        selected_channel,
        (speed_controlled_layer == selected_layer), // Allow speed control if this layer's button is held
        (pan_controlled_layer == selected_layer)    // Allow pan control if this layer's button is held
    );

    // Process playback for all non-selected layers (including speed/pan control if button held)
    for(int i = 0; i < kNumLayers; i++)
    {
        if(i != selected_layer)
        {
            // For non-selected layers, check if their speed or pan should be controlled
            bool allow_speed_for_this_layer = (speed_controlled_layer == i);
            bool allow_pan_for_this_layer = (pan_controlled_layer == i);
            if(allow_speed_for_this_layer || allow_pan_for_this_layer)
            {
                // Process with speed/pan control enabled for this layer
                layers[i].Process(
                    i, // ADC offset for this layer's volume
                    in, out, size,
                    nullptr, // No record button for non-selected layers
                    &hw,
                    layers[i].recorded_channel, // Use the channel this layer was recorded with
                    allow_speed_for_this_layer, // Allow speed control
                    allow_pan_for_this_layer    // Allow pan control
                );
            }
            else
            {
                // Normal playback only
                layers[i].ProcessPlaybackOnly(in, out, size, &hw, i);
            }
        }
    }

    UpdateLEDs();

    // Channel selection switch
    channel_button.Debounce();

    static bool last_channel_btn = false;
    bool channel_btn_pressed = channel_button.Pressed();

    if(!last_channel_btn && channel_btn_pressed)
    {
        // Custom cycling order: Guitar(1) → Mic(0) → Line(2) → Guitar(1)
        if(selected_channel == 0)      // Guitar → Mic
            selected_channel = 1;
        else if(selected_channel == 1) // Mic → Line  
            selected_channel = 2;
        else                          // Line → Guitar
            selected_channel = 0;
            
        channel_override_active = true; // User has manually changed channel
        UpdateRelays(); // Update relay state when channel button is pressed
    }
    last_channel_btn = channel_btn_pressed;

    // Bypass button: short press = bypass toggle, long press = metronome toggle
    bypass_button.Debounce();
    
    static bool last_bypass_btn = false;
    static bool metronome_toggled = false;
    bool bypass_btn_pressed = bypass_button.Pressed();
    
    // Toggle metronome on long press (>400ms)
    if(bypass_button.TimeHeldMs() > 400 && bypass_btn_pressed && last_bypass_btn)
    {
        if(!metronome_toggled)
        {
            metronome_active = !metronome_active;
            metronome_toggled = true;
            
            // Reset metronome state when activating
            if(metronome_active)
            {
                metronome_sample_counter = 0;
                metronome_beat = 0;
                click_samples_remaining = 0;
            }
        }
    }
    else
    {
        metronome_toggled = false;
    }
    
    // Toggle bypass on short press (button release before 400ms)
    if(last_bypass_btn && !bypass_btn_pressed && bypass_button.TimeHeldMs() < 400)
    {
        bypass_active = !bypass_active;
        bypass_relay.Write(!bypass_active);
    }
    
    last_bypass_btn = bypass_btn_pressed;

    UpdateChannelLEDs();
}

int main(void)
{
    SetupHardware();
    
    // Initialize hardware state to match default channel (Guitar)
    UpdateRelays();      // Set relay to correct position for Guitar
    UpdateChannelLEDs(); // Set LED to show Guitar
    
    hw.StartAudio(AudioCallback);
    while(1) {}
}

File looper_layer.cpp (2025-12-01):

#include "looper_layer.h"
#include <math.h>

void LooperLayer::Reset()
{
    record_len = 0;
    write_idx = 0;
    play_pos = 0.0f;
    recording = false;
    recorded = false;
    paused = false;
    click_count = 0;
}

void LooperLayer::Process(int adc_offset,
                          AudioHandle::InputBuffer in,
                          AudioHandle::OutputBuffer out,
                          size_t size,
                          Switch* record_play_button,
                          DaisySeed* hw,
                          int selected_channel,
                          bool allow_speed_control,
                          bool allow_pan_control)
{
    // Only process record button if provided (for selected layer)
    if(record_play_button != nullptr)
    {
        record_play_button->Debounce();

        static bool was_pressed = false;
        bool pressed = record_play_button->Pressed();

        // Start recording on long press
        if(record_play_button->TimeHeldMs() > 400 && pressed && !recording)
        {
            recording = true;
            write_idx = 0;
            recorded = false;
            paused = false;
            click_count = 0;
            speed = 1.0f; // Always start recording at normal speed
        }

        // On release
        if(was_pressed && !pressed)
        {
            if(recording)
            {
                recording = false;
                record_len = write_idx > 0 ? write_idx : 1;
                play_pos = 0.0f;
                recorded = true;
                recorded_channel = selected_channel;
            }
            else
            {
                uint32_t now = System::GetNow();
                if(now - last_release < double_click_time)
                {
                    click_count++;
                }
                else
                {
                    click_count = 1;
                }
                last_release = now;

                if(click_count == 2)
                {
                    recorded = false;
                    record_len = 0;
                    play_pos = 0.0f;
                    click_count = 0;
                    paused = false;
                }
                else if(click_count == 1)
                {
                    if(recorded)
                        paused = !paused;
                }
            }
        }
        was_pressed = pressed;
    }

    // --- Read pots for this layer ---
    // ADC layout: [0]=SPEED_POT, [1]=PAN_POT, [2]=MASTER_VOL, [3]=VOLUME1_POT, [4]=VOLUME2_POT, [5]=VOLUME3_POT, [6]=VOLUME4_POT, [7]=VOLUME5_POT
    // Potentiometers are wired backwards (3V3 and GND swapped), so readings are inverted
    float speed_pot = 1.0f - hw->adc.GetFloat(0);              // Common speed control
    float pan_pot   = 1.0f - hw->adc.GetFloat(1);              // Common pan control
    float master_vol = 1.0f - hw->adc.GetFloat(2);             // Master volume for all layers
    float vol_pot   = 1.0f - hw->adc.GetFloat(3 + adc_offset); // Individual volume per layer

    // Speed logic - only allow speed changes when explicitly enabled (hold layer button + turn speed knob)
    if(!recording && recorded && allow_speed_control)
    {
        const float center = 0.5f;
        const float dead_zone = 0.09f;
        if(speed_pot < center - dead_zone)
        {
            float tt = (speed_pot - 0.0f) / (center - dead_zone);
            speed = 0.3f + tt * (1.0f - 0.3f);
        }
        else if(speed_pot > center + dead_zone)
        {
            float tt = (speed_pot - (center + dead_zone)) / (1.0f - (center + dead_zone));
            speed = 1.0f + tt * (2.0f - 1.0f);
        }
        else
        {
            speed = 1.0f;
        }
    }
    // During recording or when speed control is not enabled, speed is locked

    // Pan logic - only allow pan changes when explicitly enabled (hold layer button + turn pan knob)
    if(!recording && recorded && allow_pan_control)
    {
        pan = pan_pot; // Read pan from knob when control is enabled
    }
    // During recording or when pan control is not enabled, pan is locked at previous value

    volume = powf(vol_pot, 2.5f) * 1.4f;  // Individual volume: 0.0 to 1.4x
    if(volume < 0.0f) volume = 0.0f;
    
    float panL = 1.0f - pan;
    float panR = pan;
    
    // Read master volume as a coefficient (0.0 to 1.43x)
    // Combined max: 1.4 * 1.43 ≈ 2.0x
    float master_volume = powf(master_vol, 2.5f) * 1.43f;
    if(master_volume < 0.0f) master_volume = 0.0f;

    // --- Input selection based on selected channel ---
    // Channel 0 = Mic (Left input), Channel 1 = Guitar (Right input), Channel 2 = Line (Both inputs)

    for(size_t i = 0; i < size; i++)
    {
        float mic_in = in[0][i];      // Left input
        float guitar_in = in[1][i];   // Right input
        
        if(recording)
        {
            if(write_idx < buffer_size)
            {
                if(selected_channel == 0) // Mic - record from left input
                {
                    buffer_l[write_idx] = mic_in;
                    buffer_r[write_idx] = mic_in;
                }
                else if(selected_channel == 1) // Guitar - record from right input
                {
                    buffer_l[write_idx] = guitar_in;
                    buffer_r[write_idx] = guitar_in;
                }
                else if(selected_channel == 2) // Line - record from both inputs (true stereo)
                {
                    buffer_l[write_idx] = mic_in;   // Left to left
                    buffer_r[write_idx] = guitar_in; // Right to right
                }
                write_idx++;
            }
            
            // Pass through during recording (DISABLED - no monitoring during recording)
            /*
            if(selected_channel == 0) // Mic
            {
                out[0][i] += mic_in * volume * master_volume;
                out[1][i] += mic_in * volume * master_volume;
            }
            else if(selected_channel == 1) // Guitar
            {
                out[0][i] += guitar_in * volume * master_volume;
                out[1][i] += guitar_in * volume * master_volume;
            }
            else if(selected_channel == 2) // Line
            {
                out[0][i] += mic_in * volume * master_volume;
                out[1][i] += guitar_in * volume * master_volume;
            }
            */
        }
        else if(recorded && record_len > 0 && !paused)
        {
            int idx0 = (int)play_pos;
            int idx1 = (idx0 + 1) % record_len;
            float frac = play_pos - idx0;

            out[0][i] += (buffer_l[idx0] * (1.0f - frac) + buffer_l[idx1] * frac) * volume * master_volume * panL;
            out[1][i] += (buffer_r[idx0] * (1.0f - frac) + buffer_r[idx1] * frac) * volume * master_volume * panR;
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

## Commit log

2025-07-15 Added MAX7219 LED Driver
2025-07-25 Added schematic
2025-08-03 Refactor: stable 2-layer looper, LED logic, modular code
2025-08-03 Add updated schematic for Daisy Loop Station
2025-08-04 Implement channel selection with button and LED indication; refactor controls
2025-08-06 Per-layer channel memory: each layer remembers channel used for recording; channel LED logic updated
2025-08-06 Add relay control and improve channel LED logic
    - Add hardware relay control for D25 (instrumental) and D26 (line)
    - Improve channel LED display logic with override functionality
    - Reorganize pin definitions to top of file for better maintainability
    - Channel LEDs now show recorded channel when switching layers
    - Allow manual channel override for re-recording without losing original channel info
    - Update relay states automatically when switching layers or channels
2025-08-06 Refactor input selection: Replace INPUT_SELECT_SW with channel-based selection
    - Remove unused INPUT_SELECT_SW (D21) pin and related GPIO
    - Simplify relay control to single CHANNEL_SWITCH_RELAY (D25)
    - Implement channel-based input selection:
    * Channel 0 (Guitar): Record from Right input (mono to stereo)
    * Channel 1 (Mic): Record from Left input (mono to stereo)
    * Channel 2 (Line): Record true stereo (Left→Left, Right→Right)
    - Update looper_layer.cpp Process() function signature
    - Relay control: OFF for Guitar/Mic, ON for Line input
    - Maintains channel memory per layer with override functionality
    [looper_layer.cpp, main.cpp]
2025-08-06 Implement individual volume controls per layer + master volume
    - Added 8-ADC setup: Speed, Pan, Master Volume + 5 individual layer volumes
    - Individual volume controls on pins D16-D20 (layers 1-5)
    - Master volume control on pin D21 affects all layers
    - Power curve scaling (^2.5): Individual 0-1.4x, Master 0-1.43x
    - Combined maximum gain limited to 2.0x (1.4 * 1.43 ≈ 2.0)
    - Updated ProcessPlaybackOnly to support per-layer volume controls
    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
2025-08-06 Implement per-layer speed and pan controls
    - Add hold-button + knob interaction for real-time speed control per layer
    - Add hold-button + knob interaction for real-time pan control per layer
    - Update Process function to accept allow_speed_control and allow_pan_control parameters
    - Add 200ms hold threshold for layer button detection
    - Speed range: 0.3x to 2.0x with center dead zone
    - Pan range: 0.0 (left) to 1.0 (right) with 0.5 (center) default
    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
2025-08-07 Update README: Add concise documentation with usage instructions
    - Streamlined project description and key features
    - Added Audio I/O and Hardware sections
    - Added comprehensive How to Use instructions:
    - Recording tracks with input selection
    - Playback controls (play/pause/clear)
    - Real-time speed and pan control via hold-button + knob
    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
2025-08-07 Update schematic files and README with hardware documentation
    - Replace old schematic PDF with rev.0.7 version
    - Add EasyEDA JSON schematic file for editing
    - Update README with direct links to schematic files
    - Add PCB and BOM status information
    - Hardware section now includes downloadable design files
2025-08-19 Update README image links and schematic to rev 0.7 (2025-08-18)
2025-10-06 Update hardware documentation: Add PCB front/back images and rev 1.0 schematic
    - Added PCB front and back side images to Hardware/PCB/
    - Updated schematic to revision 1.0
    - Updated README with PCB images and new schematic link
    - Removed old revision 0.7 schematic files
2025-10-27 Hardware fixes for PCB rev 1.0 and bypass relay feature
    - Fix inverted potentiometer readings (3V3/GND swapped on PCB)
    - Update pin assignments: Speed=D22, Pan=D21, Master=D23
    - Correct LED channel mappings to match PCB labels
    - Fix inverted relay logic for channel switching
    - Add bypass relay on D26 with button control on D27
    - Default bypass OFF (loop only), toggle with button press
    All changes tested and working with hardware rev 1.0
    [looper_layer.cpp, main.cpp]
2025-10-29 Clean up code and add bypass LED functionality
    - Remove 'HARDWARE FIX' and 'inverted logic' comments - code now matches hardware
    - Add bypass LED control on SegC Dig2 (LED_BYPASS)
    - Start with bypass ON by default
    - Reduce LED brightness to minimum (intensity 0)
    - Update channel order comments: Guitar(1) → Mic(0) → Line(2)
    - Clean up relay and potentiometer comments
    [BOM_Ouroboros_rev.1.xlsx]
2025-11-08 Add hardware documentation: PCB v1.1/1.2, 3D files, photos, and update README links
    [Ouroboros 3d Box.3mf, Ouroboros 3d Box.obj, Ouroboros 3dBox_Cura.3mf]
2025-12-01 Add metronome feature: long press bypass button, 40-250 BPM, 4/4 time with accent, LED blink
